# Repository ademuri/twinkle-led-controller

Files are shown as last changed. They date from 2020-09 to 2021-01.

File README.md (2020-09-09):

ESP32-based controller board which drives up to 10 strings of "twinkle" LED
fairy lights. These are strings of LEDs where half of the string is wired with
one polarity, and the other half with opposite polarity, so that one half or the
other (alternating down the string) can be lit up separately.

Work in progress.

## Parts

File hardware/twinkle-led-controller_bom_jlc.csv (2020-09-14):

Comment | Designator | Footprint | LCSC Part #
1uF | C1 | C_0402_1005Metric | C52923
0.1uF | C2,C7,C8,C9,C10,C11,C12,C13,C14,C15,C16 | C_0402_1005Metric | C1525
22uF | C4,C6 | C_0603_1608Metric | C59461
4.7uF | C5 | C_0603_1608Metric | C19666
D_TVS | D1 | D_SMB | C78395
LED | D2 | LED_0603_1608Metric | C2286
Q_NPN_BEC | Q1,Q2 | SOT-23 | C2150
10k | R2,R1,R3,R15 | R_0402_1005Metric | C25744
10 | R4,R5,R6,R7,R8,R9,R10,R11,R12 | R_1206_3216Metric | C17903
1k | R14 | R_0402_1005Metric | C11702
SW_Push | SW1 | SW_TACTILE_5.1MM_TS-1187A-C-D-B | C318888
AZ1117-3.3 | U1 | SOT-223 | C6186
INTERFACE-CP2102-GMR(QFN28) | U2 | QFN28G_0.5-5X5MM | C6568
HT7K1201 | U4,U5,U6,U7,U8,U9,U10,U11,U12 | SOT-23-6 | C182041

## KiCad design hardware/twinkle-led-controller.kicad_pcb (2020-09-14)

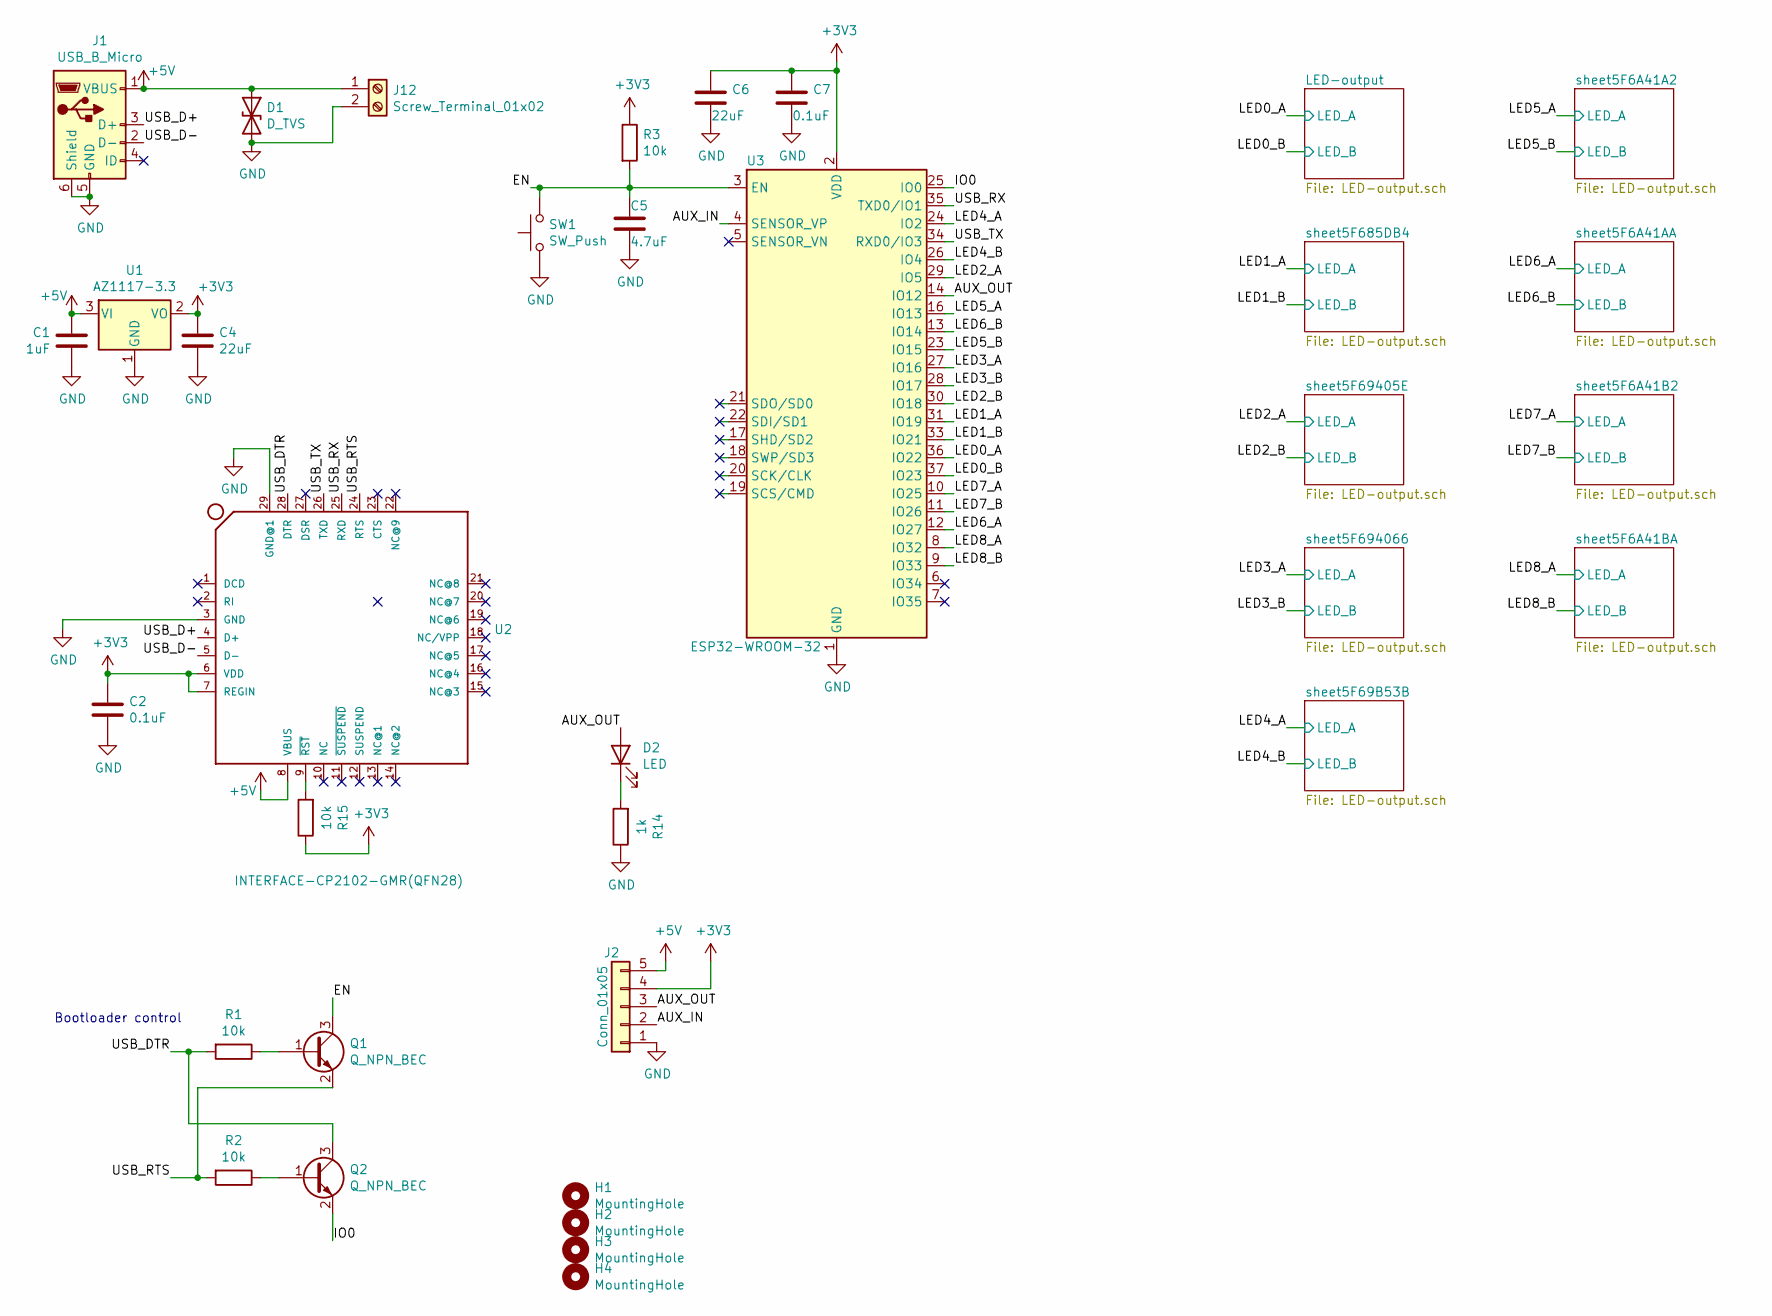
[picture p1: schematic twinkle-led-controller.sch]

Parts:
C1: 1uF; C_0402_1005Metric; LCSC C52923
C2, C7: 0.1uF; C_0402_1005Metric; LCSC C1525
C4, C6: 22uF; C_0603_1608Metric; LCSC C59461
C5: 4.7uF; C_0603_1608Metric; LCSC C19666
D1: D_TVS; D_SMB; LCSC C78395
D2: LED; LED_0603_1608Metric; LCSC C2286
H1, H2, H3, H4: MountingHole; HOLE_M4
J1: USB_B_Micro; FRAMATOME_10118194-0001LF_fixed_bridges
J2: Conn_01x05; PinHeader_1x05_P2.54mm_Vertical
J12: Screw_Terminal_01x02; Wurth_ScrewTerminal_1x02_P5.00mm_691137710002
Q1, Q2: Q_NPN_BEC; SOT-23; LCSC C2150
R1, R2, R3, R15: 10k; R_0402_1005Metric; LCSC C25744
R14: 1k; R_0402_1005Metric; LCSC C11702
SW1: SW_Push; SW_TACTILE_5.1MM_TS-1187A-C-D-B; LCSC C318888
U1: AZ1117-3.3; SOT-223; LCSC C6186
U2: INTERFACE-CP2102-GMR(QFN28); QFN28G_0.5-5X5MM; LCSC C6568
U3: ESP32-WROOM-32

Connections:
+3V3: C2.1, C4.1, C6.1, C7.1, J2.4, R3.1, R15.1, U1.2 (VO), U2.6 (VDD), U2.7 (REGIN), U3.2 (VDD)
+5V: C1.2, D1.1 (A1), J1.1 (VBUS), J2.5, J12.1, U1.3 (VI), U2.8 (VBUS); also elsewhere on the board
/AUX_IN: J2.2, U3.4 (SENSOR_VP)
/AUX_OUT: D2.2 (A), J2.3, U3.14 (IO12)
/EN: C5.1, Q1.3 (C), R3.2, SW1.2, U3.3 (EN)
/IO0: Q2.2 (E), U3.25 (IO0)
/LED0_A: U3.36 (IO22); also elsewhere on the board
/LED0_B: U3.37 (IO23); also elsewhere on the board
/LED1_A: U3.31 (IO19); also elsewhere on the board
/LED1_B: U3.33 (IO21); also elsewhere on the board
/LED2_A: U3.29 (IO5); also elsewhere on the board
/LED2_B: U3.30 (IO18); also elsewhere on the board
/LED3_A: U3.27 (IO16); also elsewhere on the board
/LED3_B: U3.28 (IO17); also elsewhere on the board
/LED4_A: U3.24 (IO2); also elsewhere on the board
/LED4_B: U3.26 (IO4); also elsewhere on the board
/LED5_A: U3.16 (IO13); also elsewhere on the board
/LED5_B: U3.23 (IO15); also elsewhere on the board
/LED6_A: U3.12 (IO27); also elsewhere on the board
/LED6_B: U3.13 (IO14); also elsewhere on the board
/LED7_A: U3.10 (IO25); also elsewhere on the board
/LED7_B: U3.11 (IO26); also elsewhere on the board
/LED8_A: U3.8 (IO32); also elsewhere on the board
/LED8_B: U3.9 (IO33); also elsewhere on the board
/USB_D+: J1.3 (D+), U2.4 (D+)
/USB_D-: J1.2 (D-), U2.5 (D-)
/USB_DTR: Q2.3 (C), R1.2, U2.28 (DTR)
/USB_RTS: Q1.2 (E), R2.2, U2.24 (RTS)
/USB_RX: U2.25 (RXD), U3.35 (TXD0/IO1)
/USB_TX: U2.26 (TXD), U3.34 (RXD0/IO3)
GND: C1.1, C2.2, C4.2, C5.2, C6.2, C7.2, D1.2 (A2), J1.5 (GND), J1.6 (Shield), J2.1, J12.2, R14.1, SW1.1, U1.1 (GND), U2.3 (GND), U2.29 (GND@1), U3.1 (GND), U3.15 (GND), U3.38 (GND), U3.39 (GND); also elsewhere on the board
unnamed: D2.1 (K), R14.2
unnamed: Q1.1 (B), R1.1
unnamed: Q2.1 (B), R2.1
unnamed: R15.2, U2.9 (~RST~)

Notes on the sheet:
Bootloader control

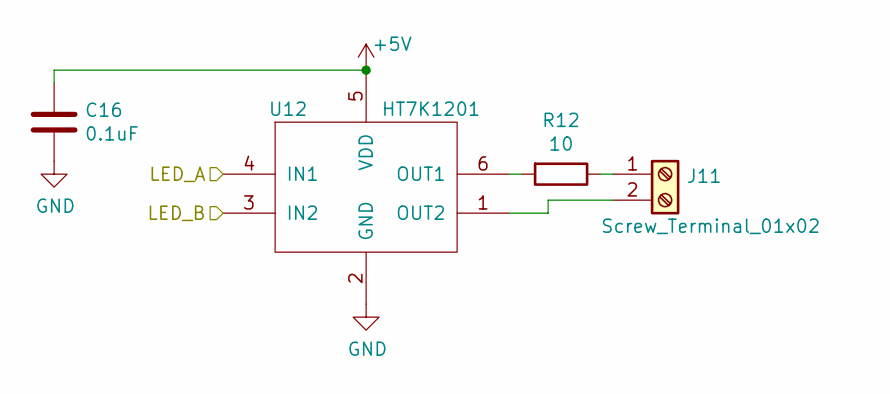
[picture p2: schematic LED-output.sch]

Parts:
C8: 0.1uF; C_0402_1005Metric; LCSC C1525
J3: Screw_Terminal_01x02; Wurth_ScrewTerminal_1x02_P5.00mm_691137710002
R4: 10; R_1206_3216Metric; LCSC C17903
U4: HT7K1201; SOT-23-6; LCSC C182041

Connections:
+5V: C8.1, U4.5 (VDD); also elsewhere on the board
/LED0_A: U4.4 (IN1); also elsewhere on the board
/LED0_B: U4.3 (IN2); also elsewhere on the board
GND: C8.2, U4.2 (GND); also elsewhere on the board
unnamed: J3.1, R4.1
unnamed: J3.2, U4.1 (OUT2)
unnamed: R4.2, U4.6 (OUT1)

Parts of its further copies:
C9, C10, C11, C12, C13, C14, C15, C16, C17: 0.1uF; C_0402_1005Metric; LCSC C1525
J4, J5, J6, J7, J8, J9, J10, J11: Screw_Terminal_01x02; Wurth_ScrewTerminal_1x02_P5.00mm_691137710002
R5, R6, R7, R8, R9, R10, R11, R12, R13: 10; R_1206_3216Metric; LCSC C17903
U5, U6, U7, U8, U9, U10, U11, U12, U13: HT7K1201; SOT-23-6; LCSC C182041

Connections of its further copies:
+5V: C9.1, C10.1, C11.1, C12.1, C13.1, C14.1, C15.1, C16.1, U5.5 (VDD), U6.5 (VDD), U7.5 (VDD), U8.5 (VDD), U9.5 (VDD), U10.5 (VDD), U11.5 (VDD), U12.5 (VDD); also elsewhere on the board
/LED1_A: U5.4 (IN1); also elsewhere on the board
/LED1_B: U5.3 (IN2); also elsewhere on the board
/LED2_A: U6.4 (IN1); also elsewhere on the board
/LED2_B: U6.3 (IN2); also elsewhere on the board
/LED3_A: U7.4 (IN1); also elsewhere on the board
/LED3_B: U7.3 (IN2); also elsewhere on the board
/LED4_A: U8.4 (IN1); also elsewhere on the board
/LED4_B: U8.3 (IN2); also elsewhere on the board
/LED5_A: U9.4 (IN1); also elsewhere on the board
/LED5_B: U9.3 (IN2); also elsewhere on the board
/LED6_A: U10.4 (IN1); also elsewhere on the board
/LED6_B: U10.3 (IN2); also elsewhere on the board
/LED7_A: U11.4 (IN1); also elsewhere on the board
/LED7_B: U11.3 (IN2); also elsewhere on the board
/LED8_A: U12.4 (IN1); also elsewhere on the board
/LED8_B: U12.3 (IN2); also elsewhere on the board
GND: C9.2, C10.2, C11.2, C12.2, C13.2, C14.2, C15.2, C16.2, U5.2 (GND), U6.2 (GND), U7.2 (GND), U8.2 (GND), U9.2 (GND), U10.2 (GND), U11.2 (GND), U12.2 (GND); also elsewhere on the board
unnamed: J4.1, R5.1
unnamed: J4.2, U5.1 (OUT2)
unnamed: J5.1, R6.1
unnamed: J5.2, U6.1 (OUT2)
unnamed: J6.1, R7.1
unnamed: J6.2, U7.1 (OUT2)
unnamed: J7.1, R8.1
unnamed: J7.2, U8.1 (OUT2)
unnamed: J8.1, R9.1
unnamed: J8.2, U9.1 (OUT2)
unnamed: J9.1, R10.1
unnamed: J9.2, U10.1 (OUT2)
unnamed: J10.1, R11.1
unnamed: J10.2, U11.1 (OUT2)
unnamed: J11.1, R12.1
unnamed: J11.2, U12.1 (OUT2)
unnamed: R5.2, U5.6 (OUT1)
unnamed: R6.2, U6.6 (OUT1)
unnamed: R7.2, U7.6 (OUT1)
unnamed: R8.2, U8.6 (OUT1)
unnamed: R9.2, U9.6 (OUT1)
unnamed: R10.2, U10.6 (OUT1)
unnamed: R11.2, U11.6 (OUT1)
unnamed: R12.2, U12.6 (OUT1)

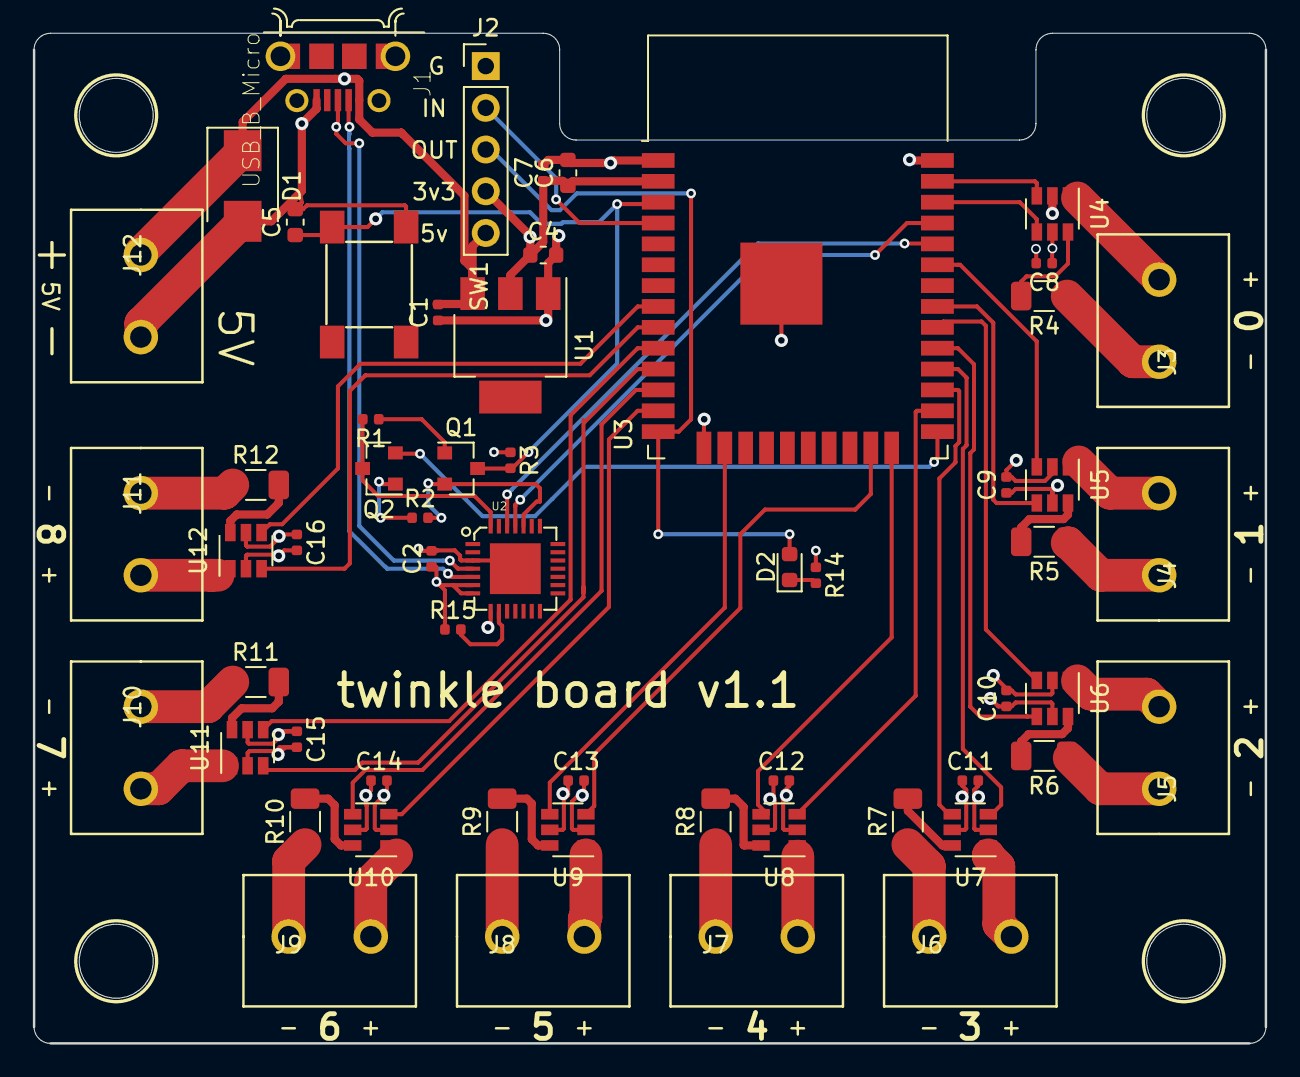
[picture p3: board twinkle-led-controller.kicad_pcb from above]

Board: 4 copper layers, 75.0 x 61.5 mm, 62 parts (0 on the bottom side), 62 nets.

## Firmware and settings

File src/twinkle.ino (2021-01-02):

#include <ArduinoJson.h>
#include <ArduinoOTA.h>
#include <ESPAsyncWebServer.h>
#include <ESPmDNS.h>
#include <PubSubClient.h>
#include <WiFi.h>
#include <WiFiClient.h>
#include <esp_wifi.h>
#include <iomanip>
#include <rom/rtc.h>
#include <string>
#include <vector>

#include "constants.h"
#include "html.h"

enum class Mode {
  kBright,
  kTwinkle,
  kHalf,
  kOff,
};

struct Strand {
  uint8_t brightness_a;
  uint8_t brightness_b;

  const int pin_0;
  const int pin_1;
};

static std::vector<Strand> strands = {
  {0, 0, 13, 15}, //1
  {0, 0, 5, 18},  //2
  {0, 0, 22, 23}, //3
  {0, 0, 27, 14}, //4
  {0, 0, 17, 16}, //5
  {0, 0, 4, 2},   //6
  {0, 0, 19, 21}, //7
  {0, 0, 33, 32}, //8
  {0, 0, 26, 25}, //9
};
static const uint8_t kNumPwmStrands = 8;

WiFiClient wifiClient;
PubSubClient pubSub(wifiClient);
AsyncWebServer server(80);

Mode mode = Mode::kOff;
uint8_t max_brightness = 255;

static const char* kMdnsName = "twinkle-controller";
static const uint32_t kRefreshMdnsDelay = 60 * 1000;

static const char* kMqttUser = "mqtt";
static const char* kMqttPassword = "mypassword";
static const char* kCommandTopic = "home/twinkle/command";

// Timer stuff, used for strand control. See the ESP32 timer example:
// https://github.com/espressif/arduino-esp32/blob/master/libraries/ESP32/examples/Timer/RepeatTimer/RepeatTimer.ino
// Used to disable task switching during ISR
portMUX_TYPE pwmTimerMux = portMUX_INITIALIZER_UNLOCKED;
portMUX_TYPE bitBangTimerMux = portMUX_INITIALIZER_UNLOCKED;
hw_timer_t * pwmTimer = nullptr;

// This is ~the fastest frequency at which the PWM/LEDC will mostly match the
// software PWM.
static const double kPwmFreq = 78125.0 / 4.0;
static const uint8_t kPwmResolution = 8;

static const int kLedPin = 12;

void IRAM_ATTR updatePwmLeds() {
  static uint8_t alternator = 0;
  static uint8_t strand_index = 0;
  static uint8_t pwm_counter = 0;

  portENTER_CRITICAL_ISR(&pwmTimerMux);
  updateBitBangLeds();

  pwm_counter++;
  if (pwm_counter > 8) {
    pwm_counter = 0;
    Strand strand = strands[strand_index];
    if (alternator == 0) {
      ledcWrite(strand_index, 0);
      ledcWrite(kNumPwmStrands + strand_index, strand.brightness_b);
    } else {
      ledcWrite(kNumPwmStrands + strand_index, 0);
      ledcWrite(strand_index, strand.brightness_a);
    }
    strand_index--;
    if (strand_index > kNumPwmStrands) {
      strand_index = kNumPwmStrands - 1;
      if (alternator == 0) {
        alternator = 1;
      } else {
        alternator = 0;
      }
    }
  }

  portEXIT_CRITICAL_ISR(&pwmTimerMux);
}

void IRAM_ATTR updateBitBangLeds() {
  static uint16_t pwm_counter = 0;
  static uint8_t alternator = 0;

  for (uint32_t i = kNumPwmStrands; i < strands.size(); i++) {
    Strand strand = strands[i];
    if (alternator == 0) {
      digitalWrite(strand.pin_0, LOW);
      digitalWrite(strand.pin_1, pwm_counter < strands[i].brightness_b);
    } else {
      digitalWrite(strand.pin_1, LOW);
      digitalWrite(strand.pin_0, pwm_counter < strands[i].brightness_a);
    }
  }
  if (alternator == 0) {
    alternator = 1;
  } else {
    alternator = 0;
    pwm_counter++;
    if (pwm_counter > 255) {
      pwm_counter = 0;
    }
  }
}

String htmlTemplateProcessor(const String &var) {
  if (var == "RESET") {
    return String(rtc_get_reset_reason(0)) + String(" ") + String(rtc_get_reset_reason(1));
  }
  return String();
}

void lightsTwinkle() {
  mode = Mode::kTwinkle;
  for (int j = 0; j < strands.size(); j++) {
    strands[j].brightness_a = 0;
    strands[j].brightness_b = 0;
  }
}

void handleMqtt(const char* topic, byte* payload, unsigned int length) {
  Serial.println("Received MQTT");
  // Assume that this is the command topic, since that's the only one we subscribe to.
  DynamicJsonDocument doc(256);
  DeserializationError error = deserializeJson(doc, payload);
  if (error) {
    Serial.printf("Failed to parse JSON: %s", error.c_str());
    return;
  }

  if (doc.containsKey("state")) {
    if (strcmp(doc["state"], "ON") == 0) {
      mode = Mode::kBright;
    } else if (strcmp(doc["state"], "OFF") == 0) {
      mode = Mode::kOff;
    }
  }

  if (doc.containsKey("effect")) {
    if (strcmp(doc["effect"], "twinkle") == 0) {
      lightsTwinkle();
    } else if (strcmp(doc["effect"], "half") == 0) {
      mode = Mode::kHalf;
    } else if (strcmp(doc["effect"], "normal") == 0) {
      mode = Mode::kBright;
    }
  }

  if (doc.containsKey("brightness")) {
    max_brightness = doc["brightness"];
  }
}

void setup() {
  // Note: setting the frequency in platformio.ini does nothing.
  setCpuFrequencyMhz(240);

  pinMode(kLedPin, OUTPUT);
  digitalWrite(kLedPin, HIGH);
  Serial.begin(115200);
  Serial.println("Booted.");
  Serial.println("");

  for (uint32_t i = 0; i < kNumPwmStrands; i++) {
    Strand strand = strands[i];
    pinMode(strand.pin_0, OUTPUT);
    pinMode(strand.pin_1, OUTPUT);
    ledcSetup(i, kPwmFreq, kPwmResolution);
    ledcAttachPin(strand.pin_0, i);
    ledcSetup(kNumPwmStrands + i, kPwmFreq, kPwmResolution);
    ledcAttachPin(strand.pin_1, kNumPwmStrands + i);
  }
  for (uint32_t i = kNumPwmStrands; i < strands.size(); i++) {
    Strand strand = strands[i];
    pinMode(strand.pin_0, OUTPUT);
    digitalWrite(strand.pin_0, LOW);
    pinMode(strand.pin_1, OUTPUT);
    digitalWrite(strand.pin_1, LOW);
  }

  Serial.print("Connecting to wifi: ");
  WiFi.setSleep(false);
  esp_wifi_set_ps(WIFI_PS_NONE);
  WiFi.begin(kSsid, kPassword);
  while (WiFi.status() != WL_CONNECTED) {
    delay(500);
    Serial.print(".");
  }
  Serial.println("Done.");
  Serial.print("IP address: ");
  Serial.println(WiFi.localIP());
  delay(500);

  ArduinoOTA
    .onStart([]() {
      // This interrupt interferes with the update process
      timerAlarmDisable(pwmTimer);

      String type;
      if (ArduinoOTA.getCommand() == U_FLASH) {
        type = "sketch";
      } else { // U_SPIFFS
        type = "filesystem";
      }

      Serial.println("Start updating " + type);
    });
  ArduinoOTA
    .onEnd([]() {
      Serial.println("\nEnd");
    });
  ArduinoOTA
    .onProgress([](unsigned int progress, unsigned int total) {
      Serial.printf("Progress: %u%%\r", (progress / (total / 100)));
    });
  ArduinoOTA
    .onError([](ota_error_t error) {
      timerAlarmEnable(pwmTimer);

      Serial.printf("Error[%u]: ", error);
      if (error == OTA_AUTH_ERROR) Serial.println("Auth Failed");
      else if (error == OTA_BEGIN_ERROR) Serial.println("Begin Failed");
      else if (error == OTA_CONNECT_ERROR) Serial.println("Connect Failed");
      else if (error == OTA_RECEIVE_ERROR) Serial.println("Receive Failed");
      else if (error == OTA_END_ERROR) Serial.println("End Failed");
    });
  ArduinoOTA.setTimeout(5 * 1000);
  ArduinoOTA.begin();

  if (MDNS.begin(kMdnsName)) {
    // Add service to MDNS-SD
    MDNS.addService("_http", "_tcp", 80);
    Serial.println("mDNS responder started");
  } else {
    Serial.println("Error setting up MDNS responder!");
  }

  server.on("/", HTTP_GET, [](AsyncWebServerRequest *request) {
    request->send_P(200, "text/html", index_html, htmlTemplateProcessor);
  });
  // Note: use POST, not PUT, so that we don't have to include the regex
  // library for URL matching, which is large
  server.on("/bright", HTTP_POST, [](AsyncWebServerRequest *request) {
    mode = Mode::kBright;
  });
  server.on("/twinkle", HTTP_POST, [](AsyncWebServerRequest *request) {
    lightsTwinkle();
  });
  server.on("/off", HTTP_POST, [](AsyncWebServerRequest *request) {
    mode = Mode::kOff;
  });

  mode = Mode::kHalf;

  server.begin();
  Serial.println("Started server.");
  digitalWrite(kLedPin, LOW);

  pwmTimer = timerBegin(0, 240, true);
  timerAttachInterrupt(pwmTimer, &updatePwmLeds, true);
  // Call at 100kHz
  timerAlarmWrite(pwmTimer, 10, /* repeat */ true);
  timerAlarmEnable(pwmTimer);

  // TODO: get MQTT server via MDNS rather than a hard-coded IP
  //pubSub.setServer(MDNS.queryHost("home-assistant"), 1883);
  pubSub.setServer("192.168.86.33", 1883);
  pubSub.setCallback(handleMqtt);
  connect();
}

void connect() {
  while (!pubSub.connected()) {
    Serial.println("Connecting to MQTT");
    if (!pubSub.connect("twinkle", kMqttUser, kMqttPassword)) {
      Serial.println("Failed to init MQTT");
      delay(5000);
      continue;
    }
    pubSub.subscribe(kCommandTopic);
  }
}

void loop() {
  ArduinoOTA.handle();

  connect();
  pubSub.loop();

  switch(mode) {
    case Mode::kBright:
      for (int i = 0; i < strands.size(); i++) {
          strands[i].brightness_a = max_brightness;
          strands[i].brightness_b = max_brightness;
      }
      break;
    case Mode::kTwinkle:
      twinkle();
      break;
    case Mode::kHalf:
        for (int j = 0; j < strands.size(); j++) {
          strands[j].brightness_a = 0;
          strands[j].brightness_b = max_brightness;
        }
      break;
    case Mode::kOff:
      for (int j = 0; j < strands.size(); j++) {
        strands[j].brightness_a = 0;
        strands[j].brightness_b = 0;
      }
      break;
    }
}

void twinkle() {
  for (int i = 0; i < strands.size(); i++) {
    const uint8_t brightness = (sin(millis()/1000.0 + i / 10.0) + 1.0)/2.0 * 256;
    if (i % 2 == 0) {
      strands[i].brightness_a = brightness;
      strands[i].brightness_b = 255-brightness;
    } else {
      strands[i].brightness_b = brightness;
      strands[i].brightness_a = 255-brightness;
    }
  }
}

void twinkle2() {
  float sinValue = sin(millis()/1000.0);
  for (int i = 0; i < strands.size(); i++) {
    strands[i].brightness_a = sinValue > 0 ? sinValue * 255 : 0;
    strands[i].brightness_b = sinValue > 0 ? 0 : sinValue * -255;
  }
}

void twinkle3() {
  for (int i = 0; i < strands.size(); i++) {
    const uint8_t brightness = (sin(millis()/1000.0 + i * 2 * 3.14 * 5.0 / 9.0) + 1.0)/2.0 * 256;
    strands[i].brightness_a = brightness;
    strands[i].brightness_b = 255-brightness;
  }
}

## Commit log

2020-08-23 First pass at schematic
    [twinkle-led-controller.kicad_pcb, twinkle-led-controller.sch]
2020-08-23 Add footprints
    [LED-output.sch, twinkle-led-controller.sch]
2020-08-25 Layout v1.0
    [LED-output.sch, twinkle-led-controller.sch]
2020-08-25 Fix v1.0 layout and generate gerbers/placement files
    - Update to CP2102, since JLCPCB doesn't have CP2104
    - Fix current-limiting resistors to 10 ohm
    [LED-output.sch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]
2020-09-05 Add PWM control for lights
2020-09-14 Hardware revision 1.1:
    - Fix pins to not use flash pins
    - Fix screw terminal footprint (holes were too small)
    - Add screw terminal for power
    - Add out for multi-unit synchronization
    [LED-output.sch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]
2020-09-15 Switch to using hardware PWM peripheral.
    This increases the effective PWM frequency to 10kHz.
2020-10-04 Blink LED during boot
2020-10-06 Disable the PWM interrupt during OTA (fixes OTA)
    [twinkle.ino]
2020-10-24 Add the reset reason to the dashboard.
    [twinkle.ino]
2020-11-15 Remove MDNS periodic refresh
    This isn't needed in most cases, and causes random reboots at uptimes of
    ~1 day. Note: I originally added this to work around MDNS issues with
    Mikrotik routers.
    [twinkle.ino]
2020-11-15 Fix LED glitches.
    Glitches were caused by reusing PWM timer when switching it between
    pins. This changes the first 8 strands to use platform support for PWM
    (note: some are hardware and some are software). The last strand is
    driven via a bit-banging interrupt.
    [twinkle.ino]
2020-11-16 Reduce glitchiness.
    This moves to having a single interrupt for both LEDC PWM and manual
    PWM. It runs the interrupt very frequently (100kHz), and only updates
    one half of one LEDC strand every interrupt. It updates the manual PWM
    strand every interrupt.
    [twinkle.ino]
